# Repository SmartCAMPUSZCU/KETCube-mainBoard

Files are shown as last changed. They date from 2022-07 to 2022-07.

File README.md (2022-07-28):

# KETCube mainBoard Repository

The KETCube platform consists of multiple parts, for the overall view on the 
KETCube platform, see the 
[KETCube documentation](https://github.com/SmartCAMPUSZCU/KETCube-docs)
repository.

This repository contains KETCube mainBoard.

**Note: the current branch may contain unverified or work-in-progress design!**

If you would like to use the latest released and proven board variant, please use the [lates release](https://github.com/SmartCAMPUSZCU/KETCube-mainBoard/releases/latest).

## About KETCube mainBoard
KETCube mainBoard is the core part of the KETCube platform.  It is 
equipped with mikroBUS<sup>TM</sup>/KETCube sockets to enable connection of
mikroBUS<sup>TM</sup> and KETCube pinout-compatible boards – see 
[KETCube datasheet](https://github.com/SmartCAMPUSZCU/KETCube-docs/blob/master/KETCubeDatasheet.pdf).

MainBoard is equipped with the Murata Type ABZ (STM32L0 MCU) module 
and HDC1080 RHT sensor, which can be used to monitor 
Relative Humidity (RH) and Temperature.

By using resources published in this repository, you can manufacture the KETCube mainBoard. 
Alternatively, you can use these materials as a starting point for a derivative work.

KETCube mainBoard was originally designed by using the Altium Designer, recently,
we introduced the completely open design in KiCAD. Design files exported from [Altium](Altium/), 
as well as the complete [KiCAD](KiCAD/) project, are available in this repository. 
Notable board variants are available directly in the directory tree: for minor fixes, see the release and commit history.

Evaluation development is covered by the content of the [Eval](Eval/) directory.

**If you would like to use the latest released and proven board variant, please use the [lates release](https://github.com/SmartCAMPUSZCU/KETCube-mainBoard/releases/latest)!**

## About KETCube

KETCube is the prototyping and demo platform developed by the SmartCAMPUS team 
at the Department of Technologies and Measurement (KET), 
The University of West Bohemia in Pilsen.

The general information about the KETCube platform can be found in 
[KETCube datasheet](https://github.com/SmartCAMPUSZCU/KETCube-docs/blob/master/KETCubeDatasheet.pdf).

More detailed info related to KETCube can be found in 
[Application Notes](https://github.com/SmartCAMPUSZCU/KETCube-docs/tree/master/appNotes).

KETCube platform

## Developed by

SmartCAMPUS ZCU (https://www.smartcampus.cz/en)
ZCU (https://www.zcu.cz/en)

See also the list of current and past 
[Contributors](https://github.com/SmartCAMPUSZCU/KETCube-mainBoard/blob/master/CONTRIBUTORS).

## License

KETCube mainBoard is distributed under the MIT-like University of Illinois/NCSA Open Source 
License. 
See also 
[LICENSE](https://github.com/SmartCAMPUSZCU/KETCube-mainBoard/blob/master/LICENSE) file.

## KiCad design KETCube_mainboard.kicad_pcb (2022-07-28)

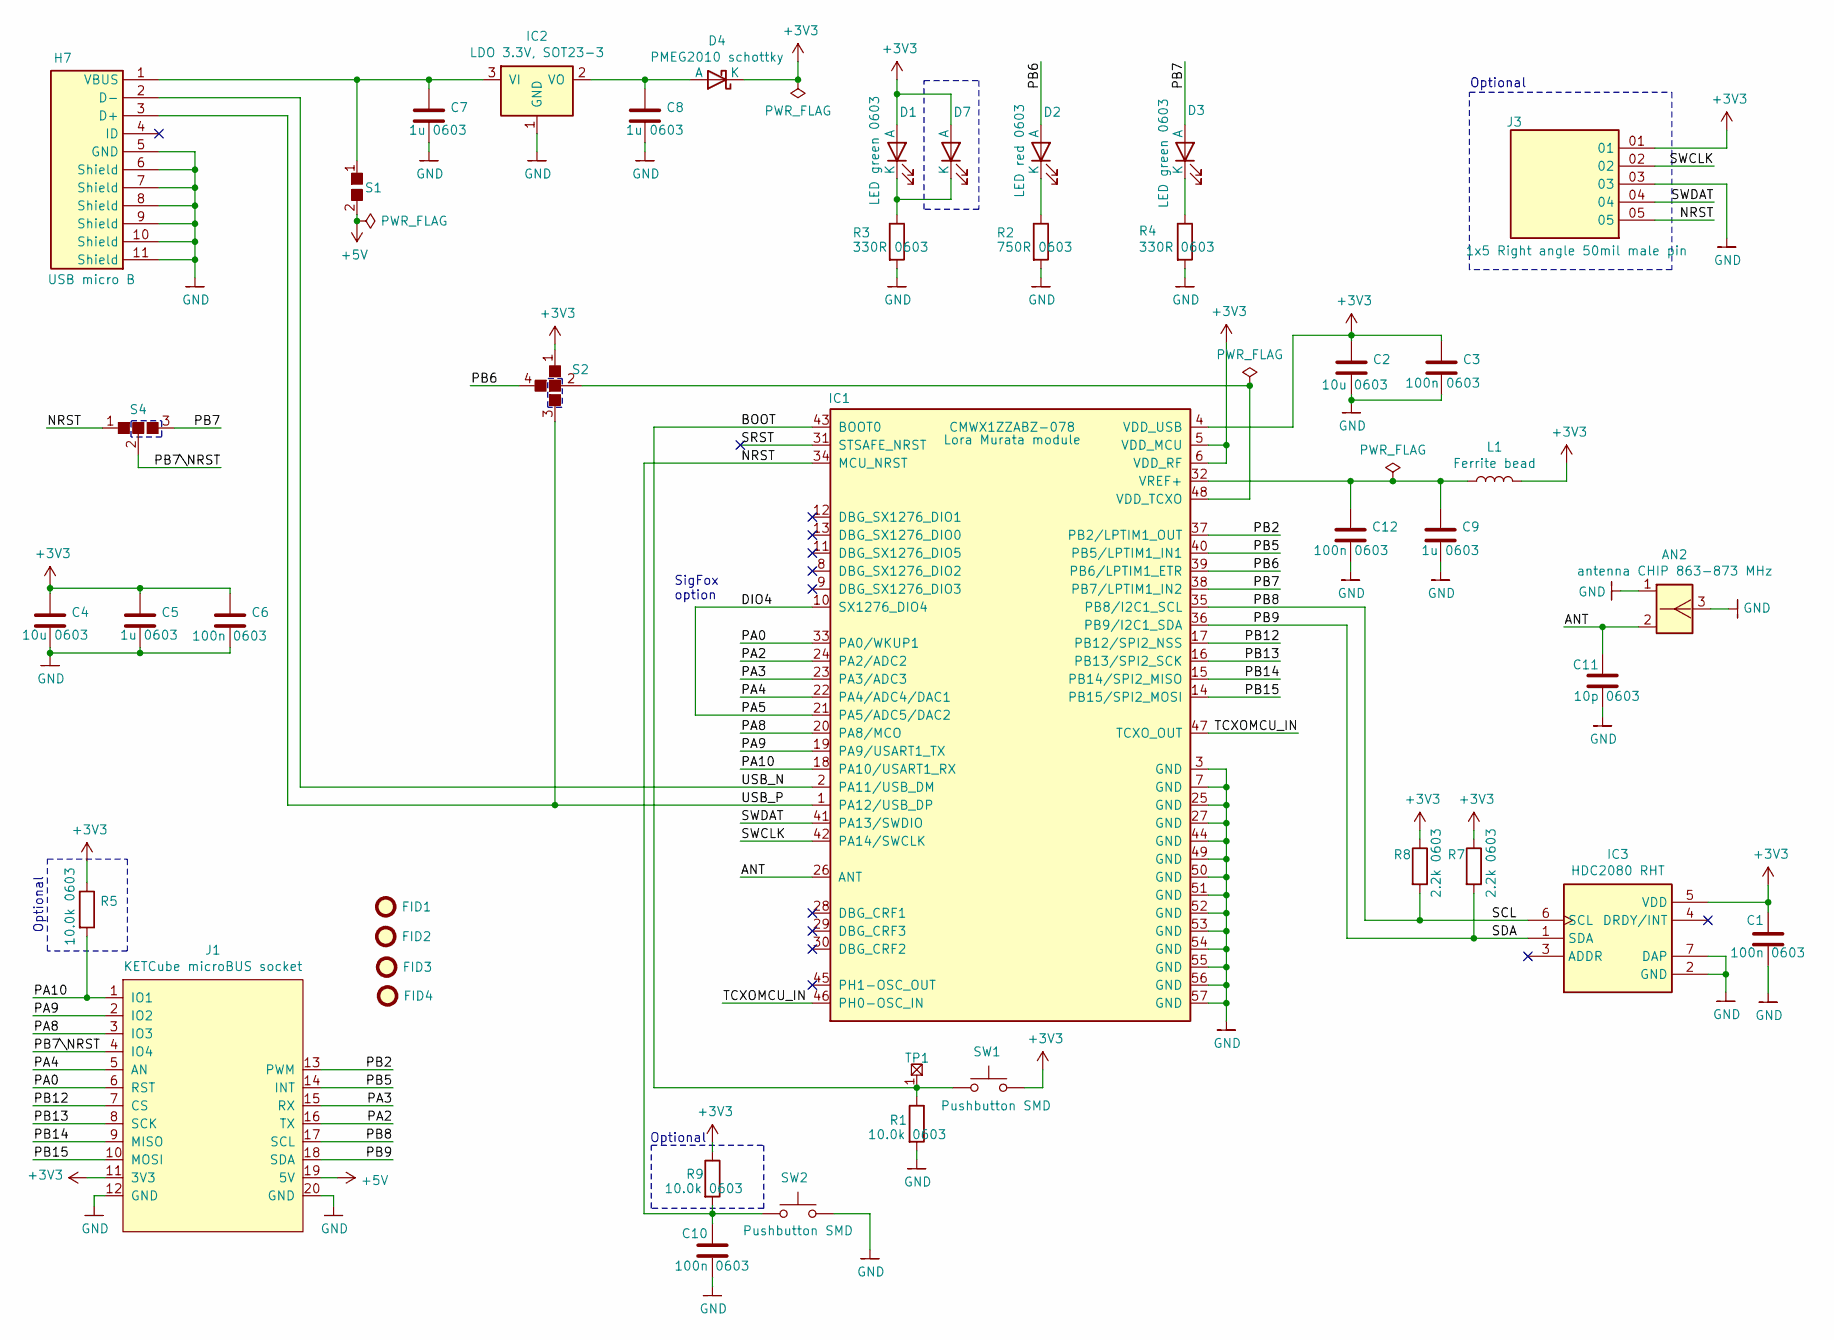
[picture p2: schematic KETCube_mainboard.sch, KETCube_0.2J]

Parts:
AN2: W3214; Pulse_W3214_10x3.2x5mm
C1, C3, C6, C10, C12: C1608X7R1H104K080AA; C_0603_1608Metric
C2, C4: GRM188R60J106KE47D; C_0603_1608Metric
C5, C7, C8, C9: C1608X7R1C105K; C_0603_1608Metric
C11: GRM1885C1H100JA01D; C_0603_1608Metric
D1, D3, D7: KPTD-1608LVZGCK; LED_0603_1608Metric
D2: KPTD-1608LVSECK-J3-PF; LED_0603_1608Metric
D4: PMEG2010AEB.115; D_SOD-523
FID1, FID2, FID3, FID4: Fiducial_D0,8mm; Fiducial_0.8mm_Mask1.6mm
H7: 47346-1001; USB_Micro-B_Hirose_ZX62WD1-B-5PC_Horizontal
IC1: CMWX1ZZABZ-078; CMWX1ZZABZ-078_12.5x11.6mm_Module
IC2: MCP1700T-3302E_TT; SOT-23
IC3: HDC2080DMBT; PWSON-6-1EP_3x3mm_P1mm
J1: KETCube_Socket_microBUS; KETCube_microBUS_32x32mm_P2.54mm_VERTICAL_THT
J3: TMS-105-02-L-S-RA; TMS-105-02-L-S-RA_1x5_P1.27_Horizontal_Offcentered_TestPads
L1: 742792664; L_0603_1608Metric
R1, R5, R9: ERJ3EKF1002V; R_0603_1608Metric
R2: ERJ3EKF7500V; R_0603_1608Metric
R3, R4: ERJ3EKF3300V; R_0603_1608Metric
R7, R8: ERJ3EKF2201V; R_0603_1608Metric
S1: SolderJumperNO; SolderJumper-2_P1.3mm_Open_TrianglePad1.0x1.5mm
S2: SolderJumper3POS; SolderJumper-4_P2.0mm_Open_TrianglePad1.0x1.5mm
S4: SolderJumper2POS; SolderJumper-3_P2.0mm_Open_TrianglePad1.0x1.5mm
SW1, SW2: Panasonic_EVQ-P7J01P
TP1: Testpoint_round_D1,4mm; TestPoint_Pad_d1,4mm

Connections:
+3V3: C1.1, C2.1, C3.1, C4.1, C5.1, C6.1, D1.2 (A), D4.2 (K), D7.2 (A), IC1.4 (VDD_USB), IC1.5 (VDD_MCU), IC1.6 (VDD_RF), IC3.5 (VDD), J1.11 (3V3), J3.01, L1.2, R5.1, R7.1, R8.1, R9.1, S2.1, SW1.2
+5V: J1.19 (5V), S1.2
/ANT: AN2.2 (FEED), C11.1, IC1.26 (ANT)
/BOOT: IC1.43 (BOOT0), R1.1, SW1.1, TP1.1
/DIO4: IC1.10 (SX1276_DIO4), IC1.21 (PA5/ADC5/DAC2)
/NRST: C10.1, IC1.34 (MCU_NRST), J3.05, R9.2, S4.1, SW2.1
/PA0: IC1.33 (PA0/WKUP1), J1.6 (RST)
/PA2: IC1.24 (PA2/ADC2), J1.16 (TX)
/PA3: IC1.23 (PA3/ADC3), J1.15 (RX)
/PA4: IC1.22 (PA4/ADC4/DAC1), J1.5 (AN)
/PA8: IC1.20 (PA8/MCO), J1.3 (IO3)
/PA9: IC1.19 (PA9/USART1_TX), J1.2 (IO2)
/PA10: IC1.18 (PA10/USART1_RX), J1.1 (IO1), R5.2
/PB2: IC1.37 (PB2/LPTIM1_OUT), J1.13 (PWM)
/PB5: IC1.40 (PB5/LPTIM1_IN1), J1.14 (INT)
/PB6: D2.2 (A), IC1.39 (PB6/LPTIM1_ETR), S2.4
/PB7: D3.2 (A), IC1.38 (PB7/LPTIM1_IN2), S4.3
/PB7\NRST: J1.4 (IO4), S4.2
/PB8: IC1.35 (PB8/I2C1_SCL), IC3.6 (SCL), J1.17 (SCL), R8.2
/PB9: IC1.36 (PB9/I2C1_SDA), IC3.1 (SDA), J1.18 (SDA), R7.2
/PB12: IC1.17 (PB12/SPI2_NSS), J1.7 (CS)
/PB13: IC1.16 (PB13/SPI2_SCK), J1.8 (SCK)
/PB14: IC1.15 (PB14/SPI2_MISO), J1.9 (MISO)
/PB15: IC1.14 (PB15/SPI2_MOSI), J1.10 (MOSI)
/SRST: IC1.31 (STSAFE_NRST)
/SWCLK: IC1.42 (PA14/SWCLK), J3.02
/SWDAT: IC1.41 (PA13/SWDIO), J3.04
/TCXOMCU_IN: IC1.46 (PH0-OSC_IN), IC1.47 (TCXO_OUT)
/USB_N: H7.2 (D-), IC1.2 (PA11/USB_DM)
/USB_P: H7.3 (D+), IC1.1 (PA12/USB_DP), S2.3
GND: AN2.1 (GND), AN2.3 (GND), C1.2, C2.2, C3.2, C4.2, C5.2, C6.2, C7.2, C8.2, C9.2, C10.2, C11.2, C12.2, H7.5 (GND), H7.6 (Shield), H7.7 (Shield), H7.8 (Shield), H7.9 (Shield), H7.10 (Shield), H7.11 (Shield), IC1.3 (GND), IC1.7 (GND), IC1.25 (GND), IC1.27 (GND), IC1.44 (GND), IC1.49 (GND), IC1.50 (GND), IC1.51 (GND), IC1.52 (GND), IC1.53 (GND), IC1.54 (GND), IC1.55 (GND), IC1.56 (GND), IC1.57 (GND), IC2.1 (GND), IC3.2 (GND), IC3.7 (DAP), J1.12 (GND), J1.20 (GND), J3.03, R1.2, R2.2, R3.2, R4.2, SW2.2
unnamed: C7.1, H7.1 (VBUS), IC2.3 (VI), S1.1
unnamed: C8.1, D4.1 (A), IC2.2 (VO)
unnamed: C9.1, C12.1, IC1.32 (VREF+), L1.1
unnamed: D1.1 (K), D7.1 (K), R3.1
unnamed: D2.1 (K), R2.1
unnamed: D3.1 (K), R4.1
unnamed: IC1.48 (VDD_TCXO), S2.2

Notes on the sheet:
Optional
SigFox option

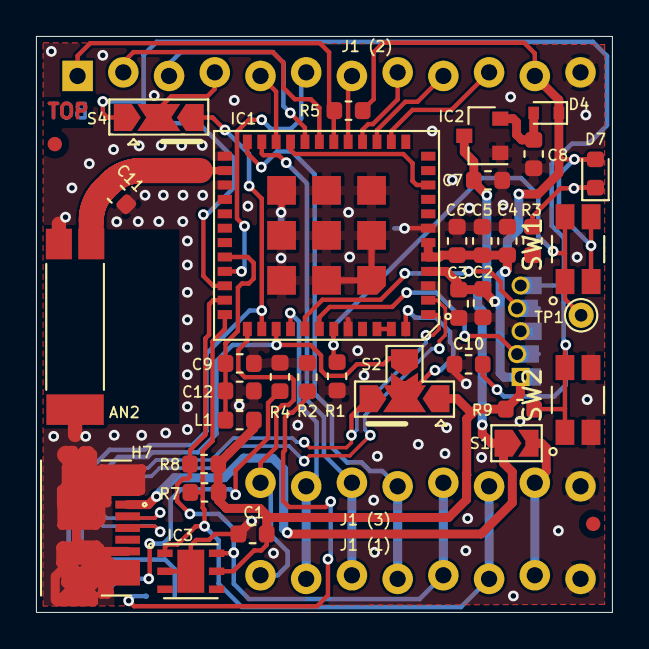
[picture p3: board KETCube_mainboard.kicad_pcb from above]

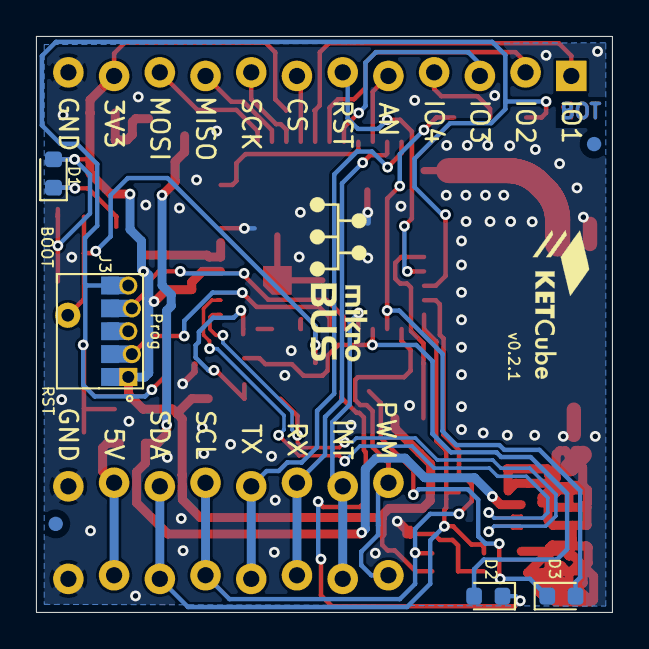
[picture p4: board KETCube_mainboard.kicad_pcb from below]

Board: 2 copper layers, 32.0 x 32.0 mm, 43 parts (6 on the bottom side), 37 nets.

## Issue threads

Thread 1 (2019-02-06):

Add 100n capacitor to NRST signal

belohoub, 2019-02-06:

belohoub, 2021-05-31:
Added to both - Altium (commit aad202790f847b3f4e3e1f52b0f487076fc78b11) and KiCAD version (commit 963a9d22d108a0ce51bb9cdfffaed91ded27a695)

Closed 2021-05-31.

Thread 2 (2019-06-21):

Add an external pull-up resistor to terminal Rx

belohoub, 2019-06-21:
KETCube terminal Rx is used to wake-up KETCube. Probably, there should be external pull-up.

belohoub, 2021-05-31:
Added to both - Altium (commit aad202790f847b3f4e3e1f52b0f487076fc78b11) and KiCAD version (commit 963a9d22d108a0ce51bb9cdfffaed91ded27a695)

Closed 2021-05-31.

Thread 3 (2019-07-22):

USB-related changes

belohoub, 2019-07-22:
- ID PIN should have 100k pull-down to work reliably in OTG configuration
- Add ESD protection circuit?

belohoub, 2019-07-22:
Follow AN4879 (https://www.st.com/content/ccc/resource/technical/document/application_note/group0/0b/10/63/76/87/7a/47/4b/DM00296349/files/DM00296349.pdf/jcr:content/translations/e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)

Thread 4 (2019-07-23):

NRST pull-up

belohoub, 2019-07-23:
Murata Type ABZ has internal reset pull-up ~45k; external pull-up R9 should be marked "optional."

belohoub, 2021-05-31:
RC pull-up is currently used for reliability

Closed 2021-05-31.

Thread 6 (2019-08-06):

OSHWA ceritication compliance

belohoub, 2019-08-06:
To be OSHWA compliant, original design files must be released - in our case, Altium design files should be released.

belohoub, 2021-05-31:
KiCAD source files were recently released - commit 963a9d22d108a0ce51bb9cdfffaed91ded27a695

Closed 2021-05-31.

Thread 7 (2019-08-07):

Remove Solder Jumper J5 and J6

belohoub, 2019-08-07:
HDC1080 can be assembled or not, additional option to connect the sensor is thus redundant.

belohoub, 2021-05-31:
Resolved by commit aad202790f847b3f4e3e1f52b0f487076fc78b11

Closed 2021-05-31.

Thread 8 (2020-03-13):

Consider HDC1080 replacement by HDC2080

belohoub, 2020-03-13:
HDC2080 is the lower-power replacement for HDC1080 with comparable parameters and currently just a little bit increased price (about $0.2 for low volumes).

belohoub, 2021-05-31:
Resolved by commit aad202790f847b3f4e3e1f52b0f487076fc78b11

Closed 2021-05-31.

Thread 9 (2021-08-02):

KETCube-LoTr review

belohoub, 2021-08-02:
1. It is possible to add GND to the top layer here, while keeping the distance (~ 6x line thickness) from the "top" radio Rx/Tx line:
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

2. I would move PIN-header description (B.Silk) to the left:
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

3. I would remove Antenna-keepout comments (Cmts.User) - these does not have any sense for this mainBoard version:
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

For 3+4 we should consider intoducing the new KETCube symbol to the library ... ?

belohoub, 2021-08-28:
The issues were resolved.

Closed 2021-08-28.

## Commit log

2018-10-17 revision E
    revision E
    [KETCube_1808_E1.GBL, KETCube_1808_E1.GBO, KETCube_1808_E1.GBP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]
2021-05-28 Repository structure: KiCAD and evaluation directories; License file update; README update
    [KETCube2_0.2HPCB_revision.GBL, KETCube2_0.2HPCB_revision.GBO, KETCube2_0.2HPCB_revision.GBP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]
2021-05-28 initial KiCAD mainboard added
    [KETCube_mainboard-B_Cu.gbr, KETCube_mainboard-B_Mask.gbr, KETCube_mainboard-B_Paste.gbr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]
2021-05-28 LoTr PIN mapping
    [PIN_Mapping.xlsx]
2021-05-31 mainBoard Atlium v0.2-revI
    [KETCube2_0.2I.GBL, KETCube2_0.2I.GBO, KETCube2_0.2I.GBP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]
2021-06-30 Eval uncompleted schematic - WIP
    [LoTr.kicad_pcb, LoTr.sch, LoTr_Connectors.sch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]
2021-06-30 Eval PCB RF part draft
    [LoTr.kicad_pcb]
2021-07-17 Initial layout
    [LoTr.kicad_pcb, LoTr_Connectors.sch, LoTr_radio.sch]
2021-07-22 PCB init version
    [LoTr.kicad_pcb, LoTr_STM32.sch]
2021-07-22 PCB DRC error fix
    [LoTr.kicad_pcb]
2021-08-01 third header added
    [LoTr.kicad_pcb, LoTr_Connectors.sch, LoTr_STM32.sch]
2021-08-07 resolved no.1 in issue #9
    [LoTr.kicad_pcb]
2021-08-18 5V LDO added
    [LoTr.kicad_pcb, LoTr_STM32.sch]
2021-08-22 design changes according to JC
    [LoTr.kicad_pcb]
2021-08-28 courtyard for template and switch causes many DRC issues; solder paste modified
    [LoTr.kicad_pcb]
2021-08-29 ctrd warnings mostly erased, resolves issue #10
    [LoTr.kicad_pcb]
2021-09-12 shield updated from library
    [LoTr.kicad_pcb, LoTr.sch, LoTr_STM32.sch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]
2021-09-20 JC+JB+OR review
    [LoTr.kicad_pcb]
2021-09-20 pin traces thickened
    [LoTr.kicad_pcb]
2021-09-27 wire fix
    [LoTr.kicad_pcb]
2022-02-27 modified according to JC
    [LoTr.kicad_pcb, LoTr_Connectors.sch, LoTr_STM32.sch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]
2022-07-28 Repository rearranged to show the mainline supporting the current design template and current KiCAD-lib
    [KETCube2_0.2HPCB_revision.GBL, KETCube2_0.2HPCB_revision.GBO, KETCube2_0.2HPCB_revision.GBP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]
